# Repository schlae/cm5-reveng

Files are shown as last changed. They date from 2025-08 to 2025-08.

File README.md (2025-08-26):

# Reverse Engineered Raspberry Pi Compute Module 5

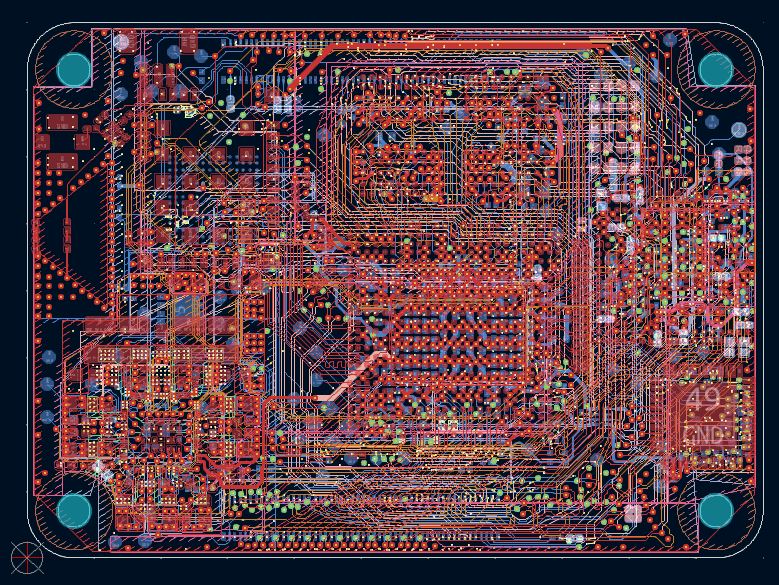
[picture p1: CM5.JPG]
Board layout with all the layers turned on


This is the reverse engineered schematic and layout for a Raspberry Pi
Compute Module 5. It's not meant to be fabricated--critical signal integrity
parameters aren't correct, it's not 100% faithful to the original, the
footprints aren't a perfect match, and the bill of materials is not
reverse engineered. You also won't be able to obtain most of the chips
since they are custom for this design or only available to large customers,
not through a distributor.

I'm sure folks will want the schematic of the regular Pi 5, but I don't
have plans to reverse engineer that.

[Schematic PDF](CM5RevEng.pdf)

[Bonus schematic of the RM0 WiFi/Bluetooth module](rpi-rm0/rpi-rm0.pdf)

## Why?

I needed to solve some design issues with a project that uses one of these
modules, but the schematic was not available. Fortunately, with a little
reverse engineering work, I was able to back out the schematic and solve my
design issues.

It's useful mainly for educational purposes or advanced hacking. For example,
now that the PMIC pinout is known, the I2C register map could be explored.
It's a great little part--if you accidentally blow up a CM5, you might be able
to remove everything except for the PMIC, program it over I2C, and use it
to power another project.

## How?

I removed all the parts from the board, measured them with an LCR meter (and
VNA, in the case of the ferrite beads), and then sanded down the board one
layer at a time, imaging each with a flatbed scanner at 9600 DPI. KiCad layout
lets you embed images which is great for tracing.

## Fun Trivia

The resistors in the upper right corner that select the memory and eMMC
configuration are not zero-ohm devices. Each possible position has a specific
resistor value, forming a resistor divider with a 10K resistor, so that
the RP1 can measure the voltage with two ADC inputs and determine the
configuration.

The board has 10 layers. It is what's known as a 2+6+2 configuration since
it has four layers of microvias: layer 1-2, 2-3, 8-9, and 9-10. There are
buried mechanical vias from layers 2-9, and standard through-board vias
from layers 1-10.

The PMIC has a hot-swap function to limit the inrush current to the
\>350uF of capacitance on the 5V rail. External capacitance on the carrier
board is probably unnecessary.

The WiFi and Bluetooth functions can be disabled (through GPIO) from the
BCM2712 as well as the connector pins. You can detect this externally
by monitoring the voltages on the BT\_nDISABLE and WL\_nDISABLE pins.

The CM5 with onboard eMMC will not conflict with an external SD card (wired
to the pins on the connector). This is because the SD pins are unconnected on
this version of the module.

The original board has no designators, so the ones in this design are
made up, with the exception of the test points, which are documented
in the official RPi datasheet.

The 5V input goes through a hot-swap circuit with a series pass MOSFET. Since
there is a test point on either side of the MOSFET and the part number is
known (DMG7430LFG), you could monitor the voltage across and compute the
supply current based on the MOSFET RDSON.

## Board Stackup

By very carefully sanding through the board one layer at a time, I figured
out the approximate stackup using digital calipers.

| Layer | | Approximate Thickness (mm) | Function |
|---|-|---|---|
| 1 | Cu | 0.0522 | Top layer |
| | PP | 0.0450 | |
| 2 | Cu | 0.0522 | Ground, PMIC LX, some signals. Reference layer for 1 and 3. |
| | PP | 0.0600 | |
| 3 | Cu | 0.0348 | Signal and power. |
| | PP | 0.1400 | |
| 4 | Cu | 0.0348 | Ground. |
| | Core | 0.0600 | |
| 5 | Cu | 0.0522 | Power, limited signal. |
| | PP | 0.1176 | |
| 6 | Cu | 0.0522 | Power. |
| | Core | 0.0600 | |
| 7 | Cu | 0.0348 | Ground. |
| | PP | 0.1400 | |
| 8 | Cu | 0.0348 | Signal and power. |
| | PP | 0.0348 | |
| 9 | Cu | 0.0522 | Ground. Reference layer for 8 and 10. |
| | PP | 0.0450 | |
| 10 | Cu | 0.0522 | Bottom layer | 

## Updated Test Point List

The Raspberry Pi Compute Module 5 datasheet has a table of test points, but
most of them are listed as "reserved." Here's a complete table. The coordinates
are relative to the lower left corner of the board (if the board had
a rectangular corner instead of being rounded off), increasing to the right
and upwards. Note that, in the KiCad layout, the lower left corner
is at 100mm x 100mm, and the Y axis is flipped, decreasing as you move
up. To change a coordinate from this table to KiCad, add 100 to the X
coordinate, and subtract the Y coordinate from 100.

| Reference | X | Y | NAME | DESCRIPTION |
|---|---|---|---|---|
| MH4 | 51.5  | 36.5  | Mounting Hole | |
| MH3 |  3.5  | 36.5  | Mounting Hole | |
| MH2 | 51.5  |  3.5  | Mounting Hole | |
| MH1 |  3.5  |  3.5  | Mounting Hole | |
| TP1 | 14.34 | 17.54 | +5V | Raw 5V power to board. |
| TP2 |  8.8  |  1.3  | RUN | Unknown PMIC status output, possibly power good. |
| TP3 | 51.2  | 32.6  | GND |
| TP4 |  4.8  | 13 | PMIC INT | PMIC interrupt output (likely). |
| TP7 | 24.2  |  7.5  | GND |
| TP8 |  1.65 | 15.05 | GND |
| TP9 |  1.5  | 10.05 | VREF\_3V3 | Analog 3.3V to RP1 for ADCs. |
| TP10 | 48.4  | 15.1  | VREG | Unknown regulated voltage to RP1. |
| TP13 | 42.6  |  7.3  | GND |
| TP15 | 14.7  |  6.6  | VDD\_0V8\_LDO | 0.8V LDO regulator to BCM2712. |
| TP16 |  9.3  | 34.9  | nRPIBOOT | Hold low for boot mode. |
| TP17 | 37.4  |  8.1  | VDD\_3V3\_2 | Secondary 3.3V rail for NOR flash and eMMC. |
| TP21 | 24.5125 | 14.025 | nRESET\_OUT | BCM2712 reset output (status). |
| TP22 | 13.0875 | 11.225 | PMIC\_SIG | Unknown PMIC signal. Could be for PMIC OTP programming. |
| TP26 | 17.7  | 20.2  | GND |
| TP27 | 43.6  | 22.3  | VDD\_1V1\_RP1 | RP1 1.1V core voltage supply. |
| TP28 | 15.4  | 16 | VDD\_BCM\_CORE | BCM2712 core voltage rail. Nominally 0.8V. |
| TP29 | 23.65 | 21.55 | VDD\_0V8\_BCM | BCM2712 auxiliary 0.8V rail. |
| TP30 | 37.2  | 34.9  | VDD\_0V6 | LPDDR4 VDDQ supply. |
| TP31 |  9.1  |  3.2  | VDD\_1V1 | LPDDR4 VDD2 supply. |
| TP32 |  1.5  | 13 | VDD\_3V7\_WIFI | 3.7V rail for WiFi radio. |
| TP33 | 47 | 36 | CM5\_3V3 | Main 3.3V supply rail. |
| TP34 | 50.5  | 15.5  | CM5\_1V8 | Main 1.8V supply rail. |
| TP35 | 11 | 37.8  | DEBUG\_UART\_TX | Debugging UART transmit output. |
| TP36 |  8.5  | 37.1  | DEBUG\_UART\_RX | Debugging UART receive input. |
| TP39 | 22.1  |  6.1  | EN\_LOAD\_SWITCH | Enables VDD\_3V3\_2 and VDD\_1V8\_2 when asserted. |
| TP40 |  6.7  | 15.2  | PMIC\_SCL | PMIC I2C bus clock. |
| TP41 |  8.7  | 15.3  | PMIC\_SDA | PMIC I2C bus data. |
| TP42 | 11.4  | 34.9  | PWR\_BUT | Power button signal to PMIC. |
| TP44 | 51.7  | 30.2  | VDD\_2V5\_RP1 | RP1 internal voltage regulator: 2.5V supply. |
| TP45 | 53.1  | 28.7  | VDD\_1V1\_RP1 | RP1 internal voltage regulator: 1.1V supply. |
| TP46 |  7 | 34.7  | GND |
| TP48 | 21.6  | 15.4  | SOC\_TRST\_N | BCM2712 JTAG test reset input. |
| TP49 | 21.6  | 13.3  | SOC\_TDI | BCM2712 JTAG test data input. |
| TP50 | 20.4  | 17.2  | SOC\_TDO | BCM2712 JTAG test data output. |
| TP51 | 20.3  |  8.8  | SOC\_TMS | BCM2712 JTAG test mode select. |
| TP52 | 19.9  | 11.9  | SOC\_TCK | BCM2712 JTAG test clock. |
| TP57 | 53.2  | 32 | RP1\_TP | Unknown RP1 signal. |
| TP60 | 48 | 38.7  | GND |
| TP61 | 6.575 | 1.225 | GND |
| TP62 | 22.2  | 31.6  | GND |
| TP63 |  8.7  | 18.2  | 5V\_SENSE | Main board 5V rail, after hot-swap/inrush limiting MOSFET. |
| TP64 | 47.3  |  5.4  | VDD\_1V0\_PHY | BCM54210 internal voltage regulator: 1.0V supply. |
| TP65 | 28.2  |  7.5  | USBC\_D\_N | BCM2712 USB 2.0. |
| TP66 | 26.1  |  7.5  | USBC\_D\_P | BCM2712 USB 2.0. |
| TP67 |  7 | 38.6  | LED\_nPWR | Power LED, driven by RP1. |
| TP68 | 13 | 37.5  | LED\_nACT | Activity LED, driven by BCM2712. |
| TP69 | 38.8  | 25.9  | ETH0\_P |
| TP70 | 39.6  | 24.2  | ETH0\_N |
| TP71 | 43.8  | 14.1  | ETH1\_N |
| TP72 | 45.6  | 13.1  | ETH1\_P |
| TP73 | 42.4  | 31.7  | ETH2\_P |
| TP74 | 42.6  | 33.7  | ETH2\_N |
| TP75 | 41.6  | 37.8  | ETH3\_P |
| TP76 | 42.9  | 36.1  | ETH3\_N |
| TP77 | 14.37 | 19.52 | +5V | Raw 5V power to board. |

## RP1 Pinout Mysteries

There are some pins that have not been identified because they're not connected
on the CM5:

| Pin | Guess |
|-----|---|
| A2  | |
| B3  | |
| C2  | |
| C3  | |
| C4  | |
| D1  | |
| E3  | |
| E10  | |
| E15  | |
| F1  | |
| F2  | |
| F3  | |
| F7  | |
| G1  | |
| G2  | |
| H1  | |
| H3  | |
| H7  | |
| H17 | USB 2.0? |
| H18 | USB 2.0? |
| J15  | |
| J17  | |
| L13  | |
| L15  | |
| M17  |USB 2.0? |
| M18  |USB 2.0? |
| R4  | |
| T3  | |
| T4  | |
| T13  | |
| T14  | |
| V2  | |
| V3  | |

## Future Work

* PCIe (BCM2712 to RP1) net identification
* RP1 to BCM2712 net identification
* PMIC I2C register map

## License

[CC BY-SA 4.0](https://creativecommons.org/licenses/by-sa/4.0)

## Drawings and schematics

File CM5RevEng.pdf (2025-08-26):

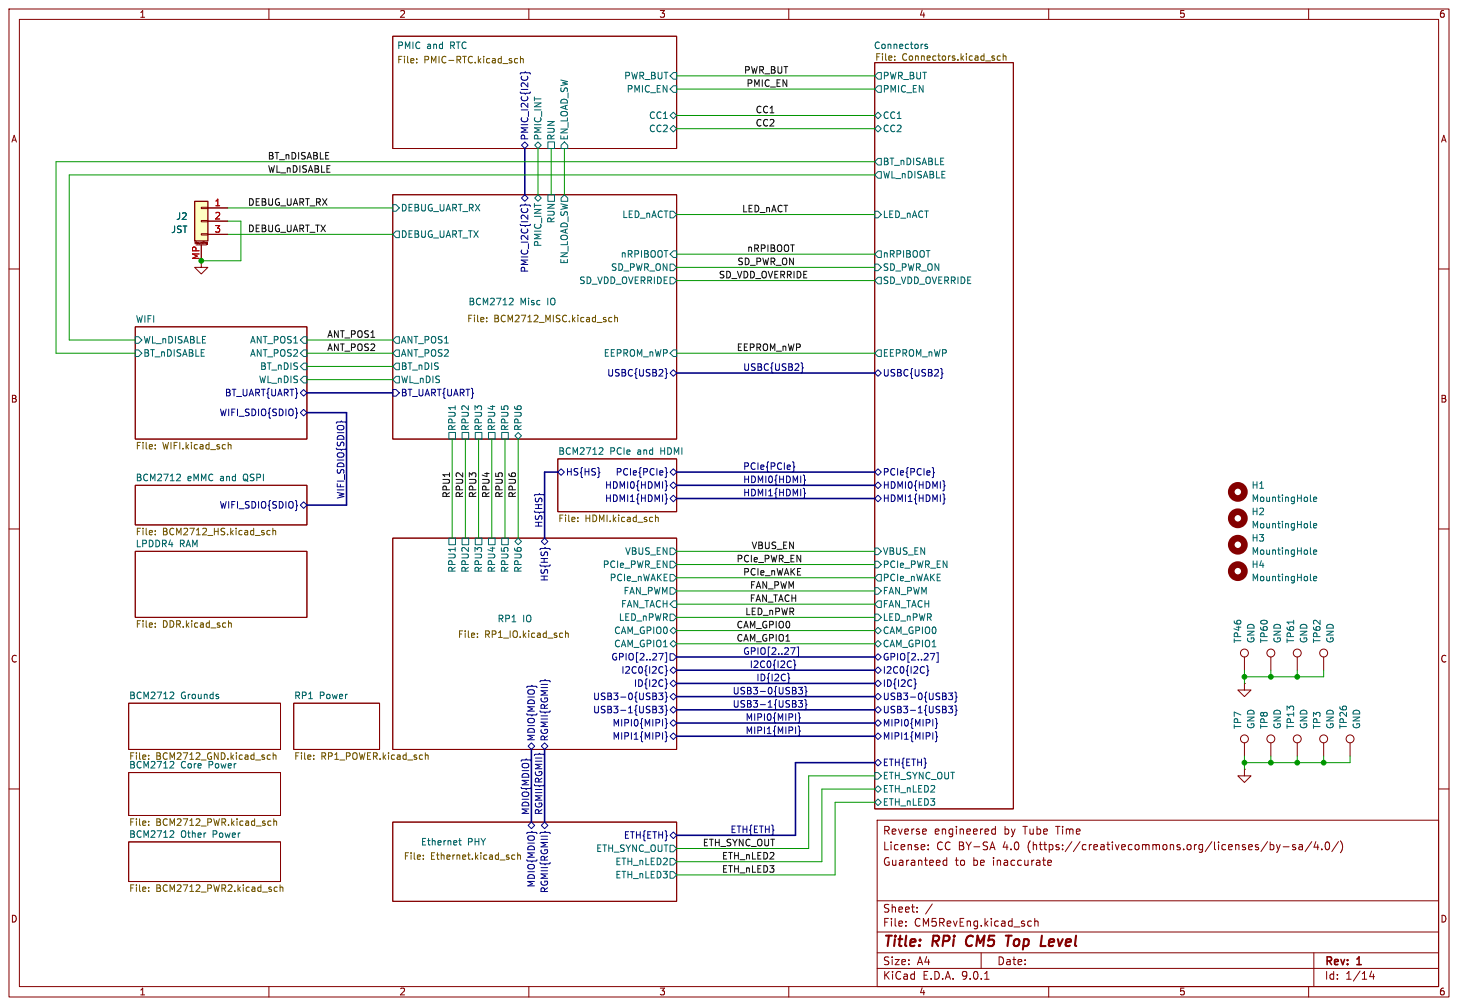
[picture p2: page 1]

File: RP1_IO.kicad_sch WIFI_SDIO{SDIO} BCM2712 eMMC and QSPI File: BCM2712_HS.kicad_sch BT_nDISABLE

H1 MountingHole TP3 GND TP26 GND TP61 GND TP62 GND

H4 MountingHole H3 MountingHole H2 MountingHole TP46 GND

ID{I2C} MDIO{MDIO} RGMII{RGMII} RP1 IO

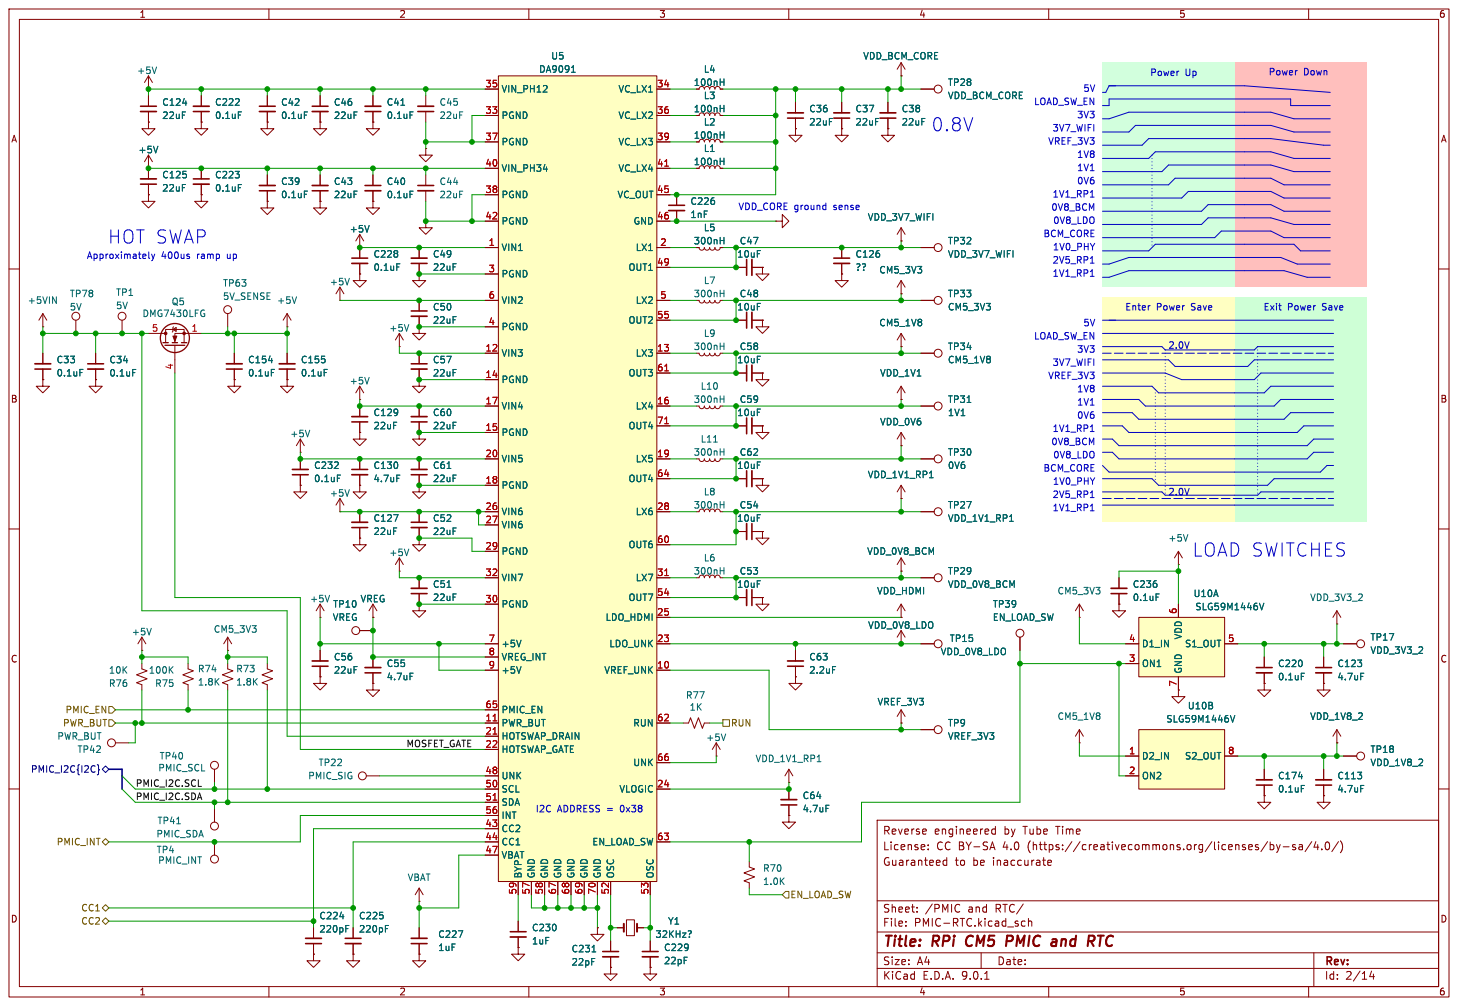
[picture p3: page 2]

Id: 2/14 Title: RPi CM5 PMIC and RTC

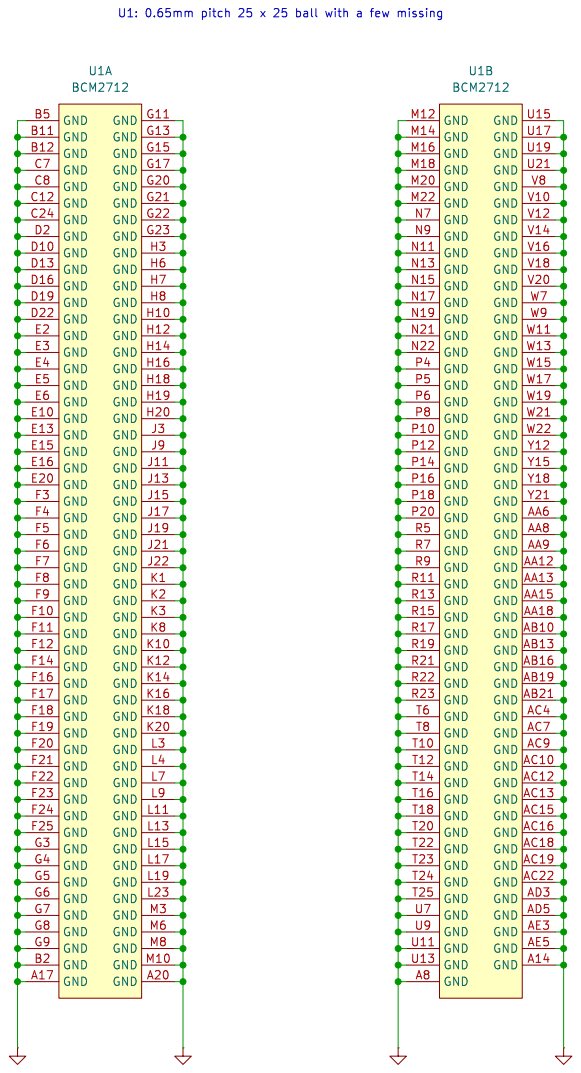
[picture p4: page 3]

BCM2712 GND J9 GND J11 GND J13 GND J15 GND J17 GND J19 GND J21 GND J22 GND K1 GND K2 GND K3 GND K8 GND K10 GND K12 GND K14 GND K16 GND K18 GND K20 GND L3 GND L4 GND L7 GND L9 GND L11 GND L13 GND L15 GND L17 GND L19 GND L23 GND M3 GND M6 GND M8 GND M10
GND B5 GND B11 GND B12 GND C7 GND C8 GND C12 GND C24 GND D2 GND D10 GND D13 GND D16 GND D19 GND D22 GND E2 GND E3 GND E4 GND E5 GND E6 GND E10 GND E13 GND E15 GND E16 GND E20 GND F3 GND F4 GND F5 GND F6 GND F7 GND F8 GND F9 GND F10 GND F11 GND F12 GND F14 GND F16 GND F17 GND F18 GND F19 GND F20 GND F21 GND F22 GND F23 GND F24 GND F25 GND G3 GND G4 GND G5 GND G6 GND G7 GND G8 GND G9 GND B2 GND A17

BCM2712U1: 0.65mm pitch 25 x 25 ball with a few missing
GND G11 GND G13 GND G15 GND G17 GND G20 GND G21 GND G22 GND G23 GND H3 GND H6 GND H7 GND H8 GND H10 GND H12 GND H14 GND H16 GND H18 GND H19 GND H20 GND J3 GND A20

Id: 3/14 Title: RPi CM5 BCM2712 Grounds

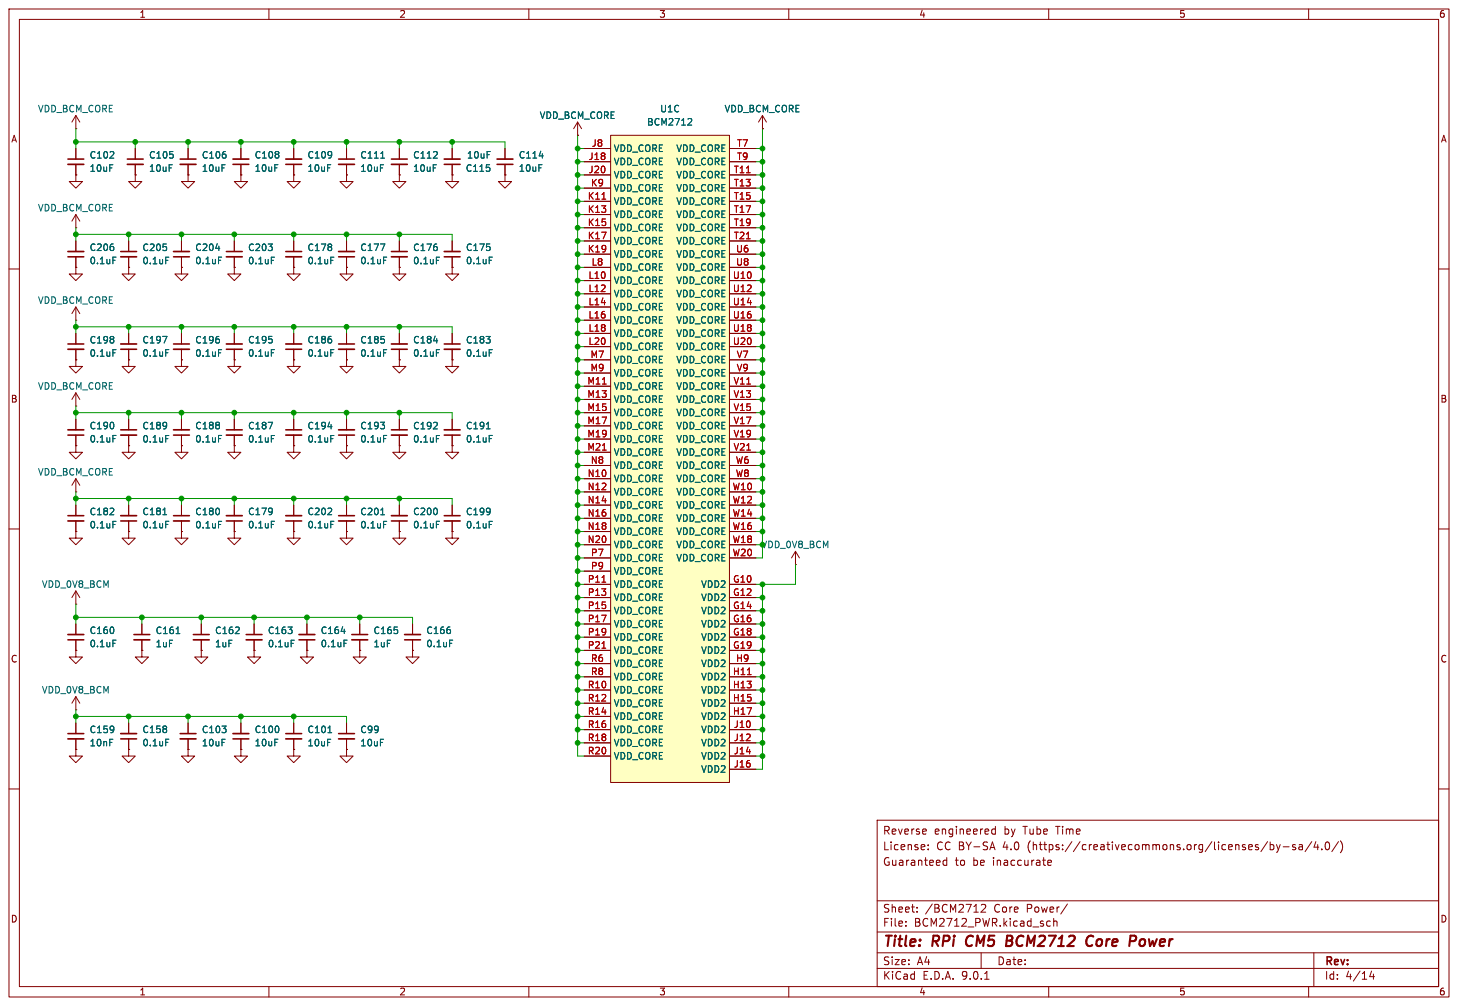
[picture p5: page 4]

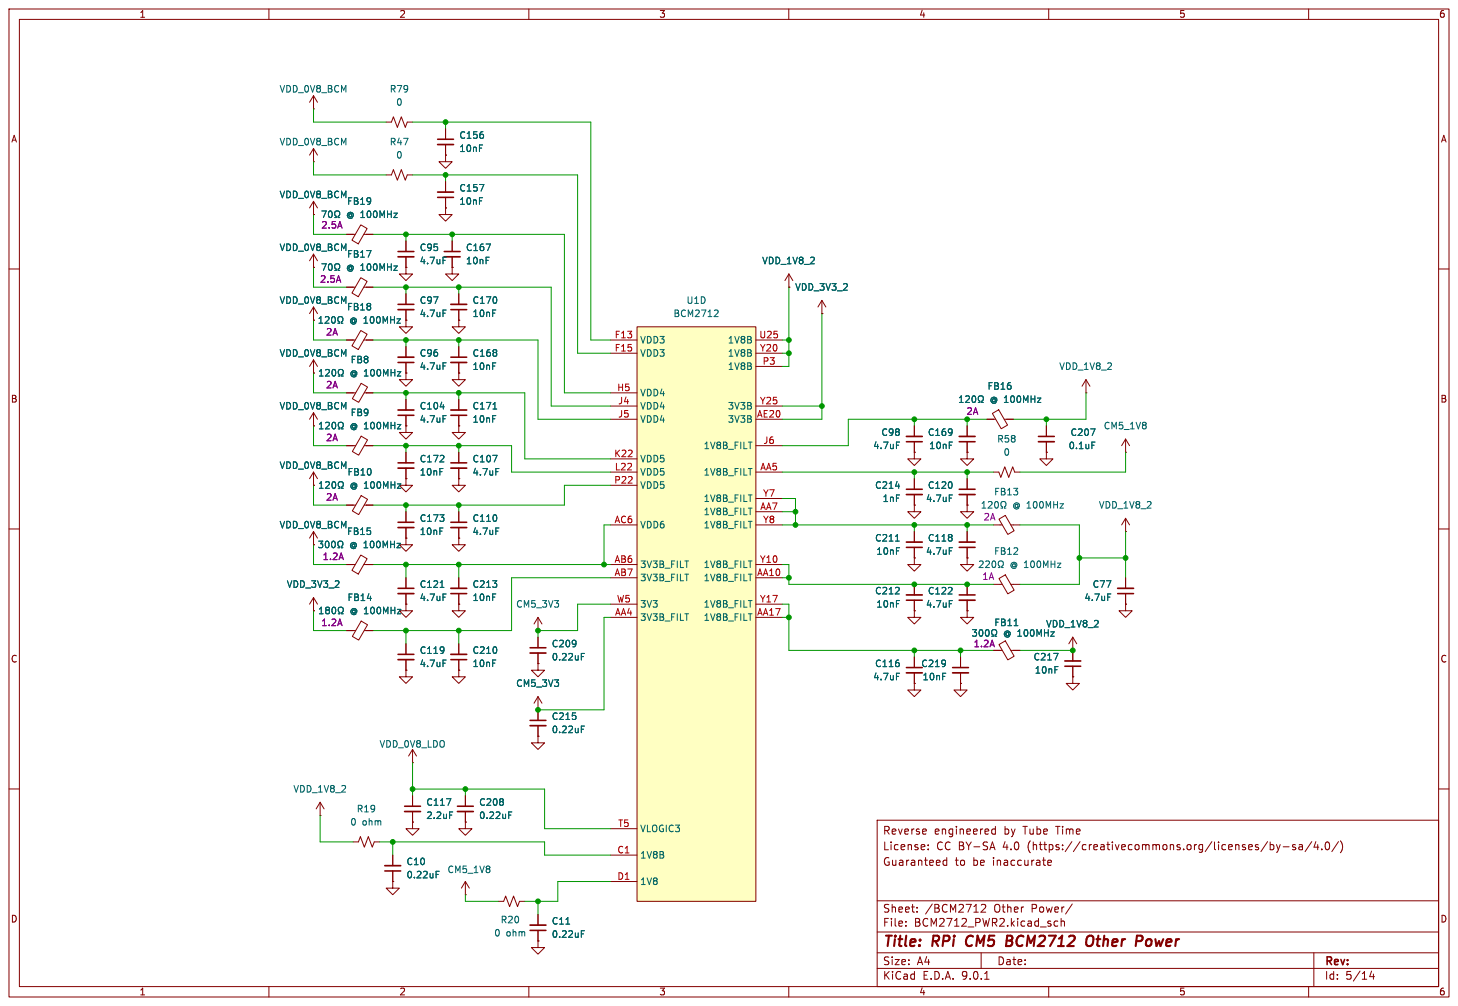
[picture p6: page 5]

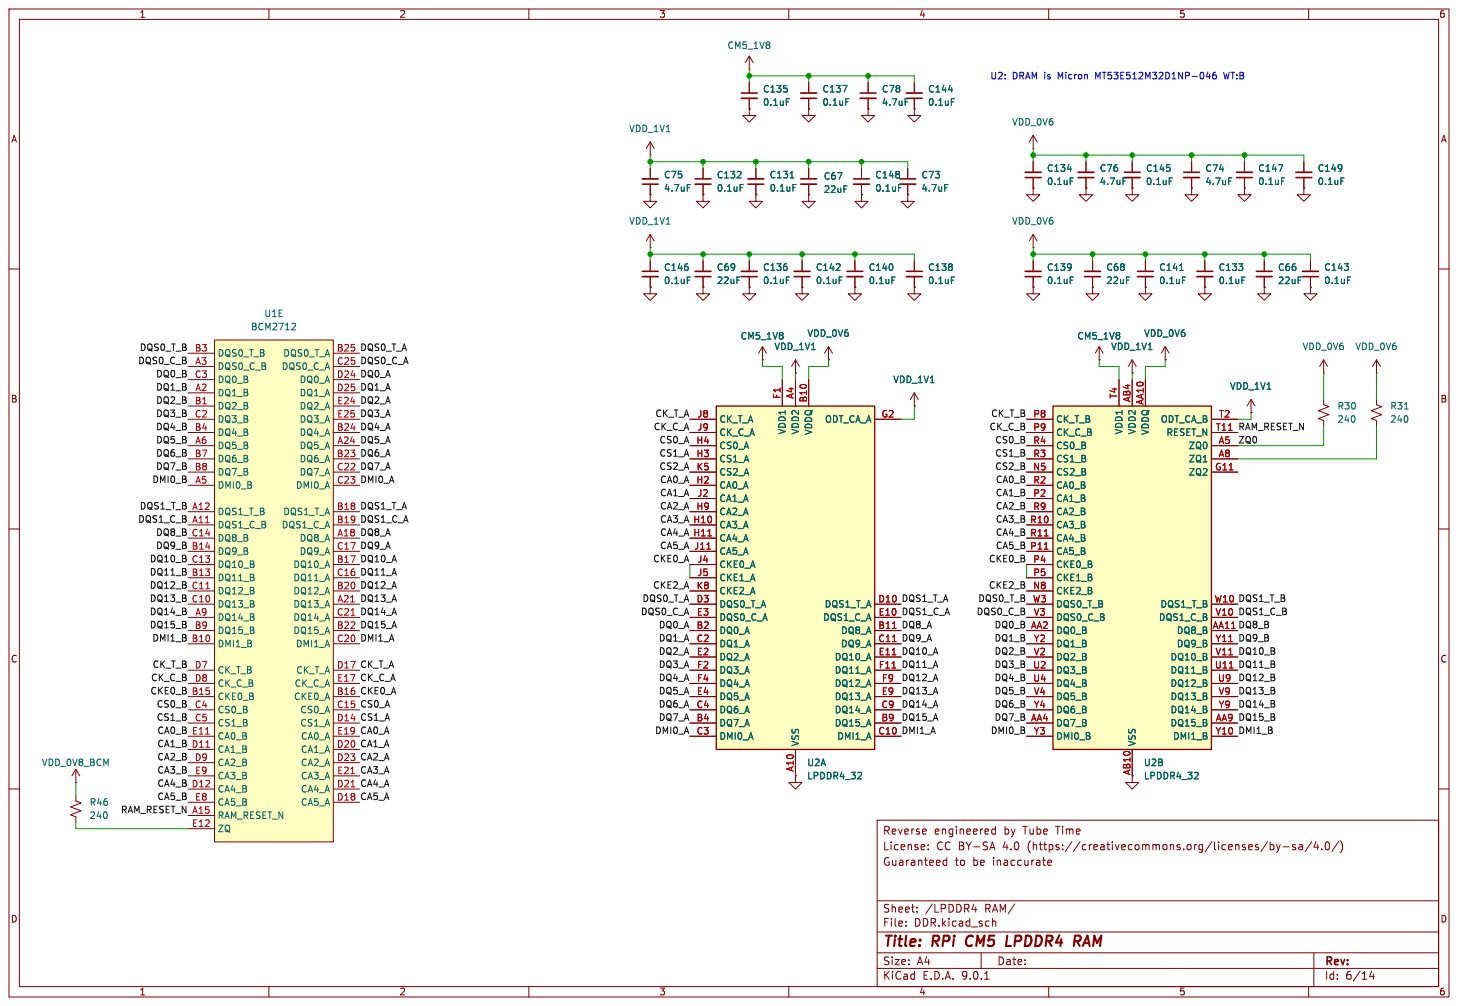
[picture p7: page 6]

Id: 6/14 Title: RPi CM5 LPDDR4 RAM

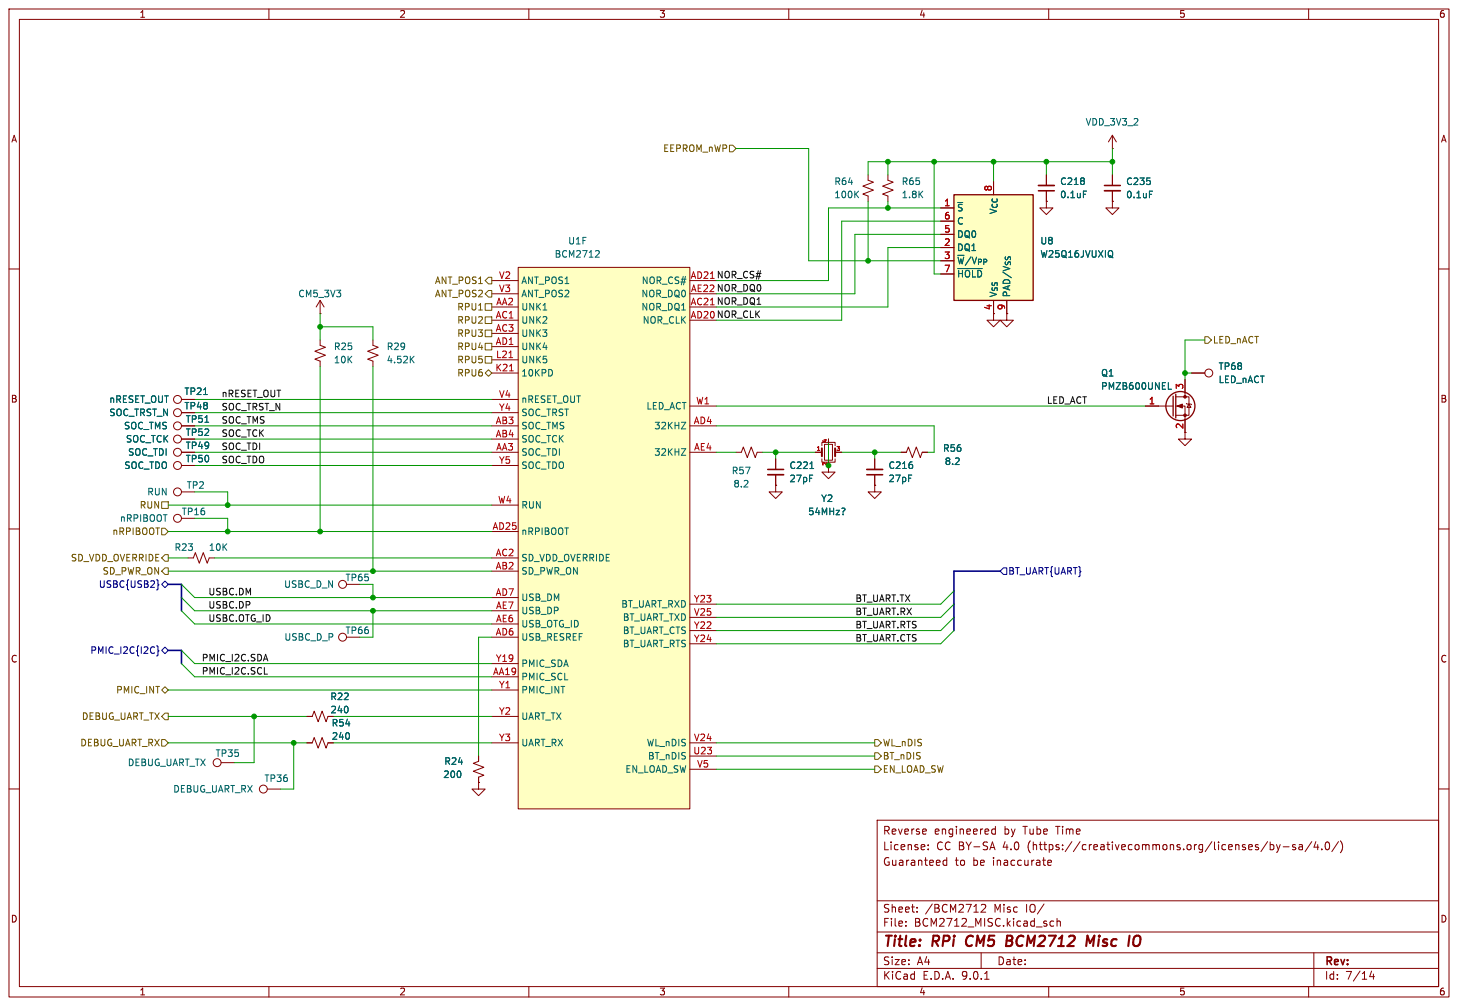
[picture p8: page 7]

PMIC_I2C.SDA USBC.DP USBC.OTG_ID

Id: 7/14 Title: RPi CM5 BCM2712 Misc IO

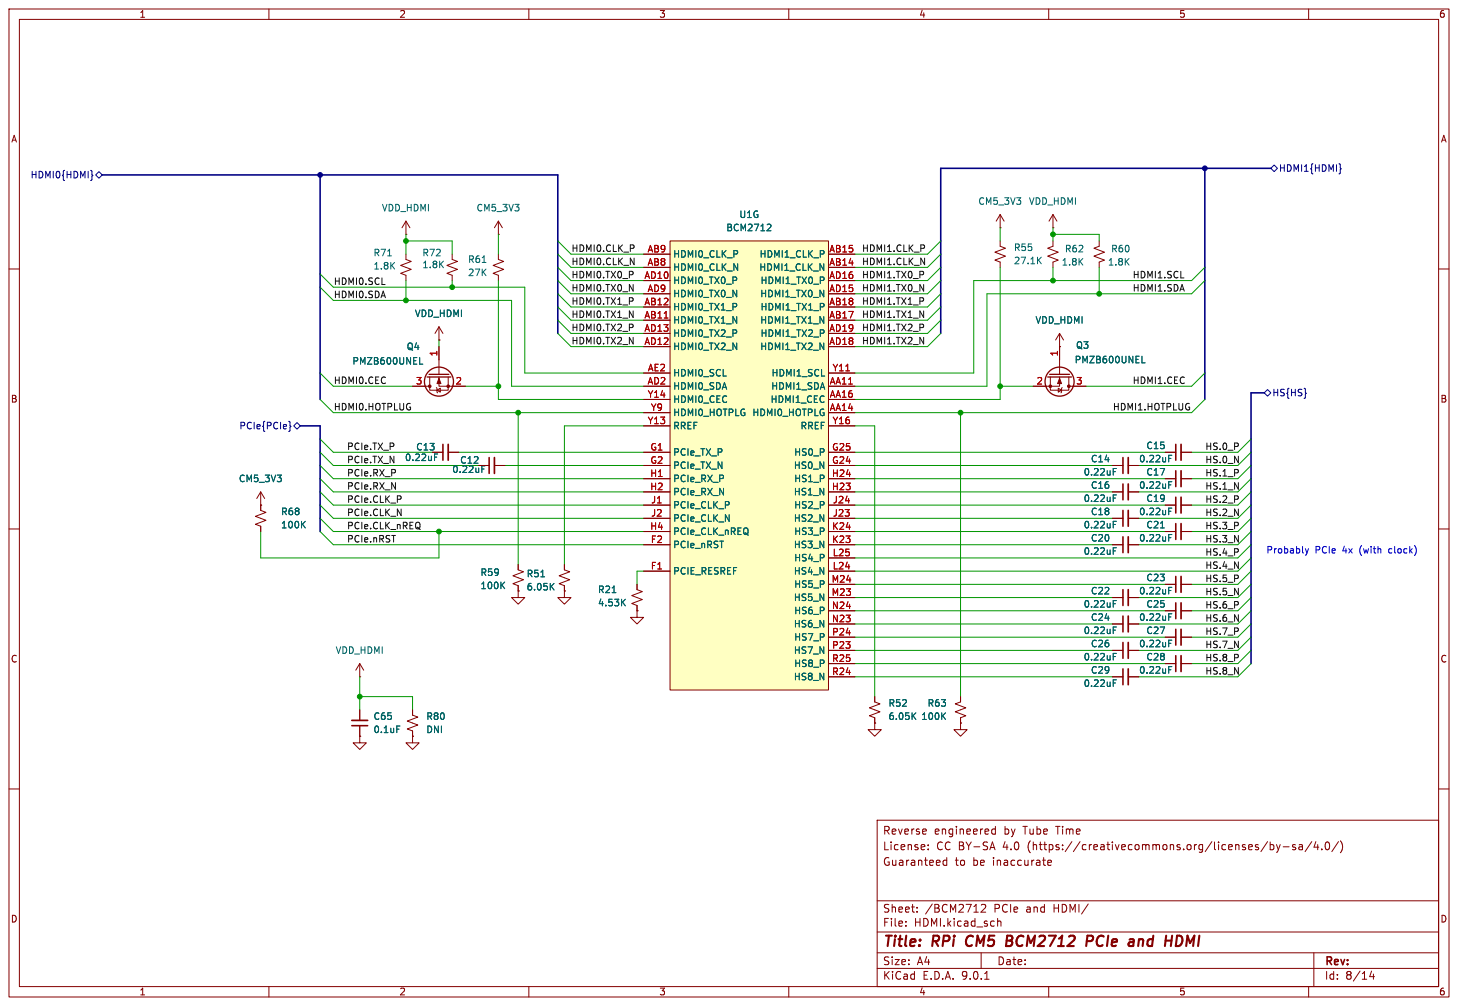
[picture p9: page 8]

Probably PCIe 4x (with clock) Q3 PMZB600UNEL

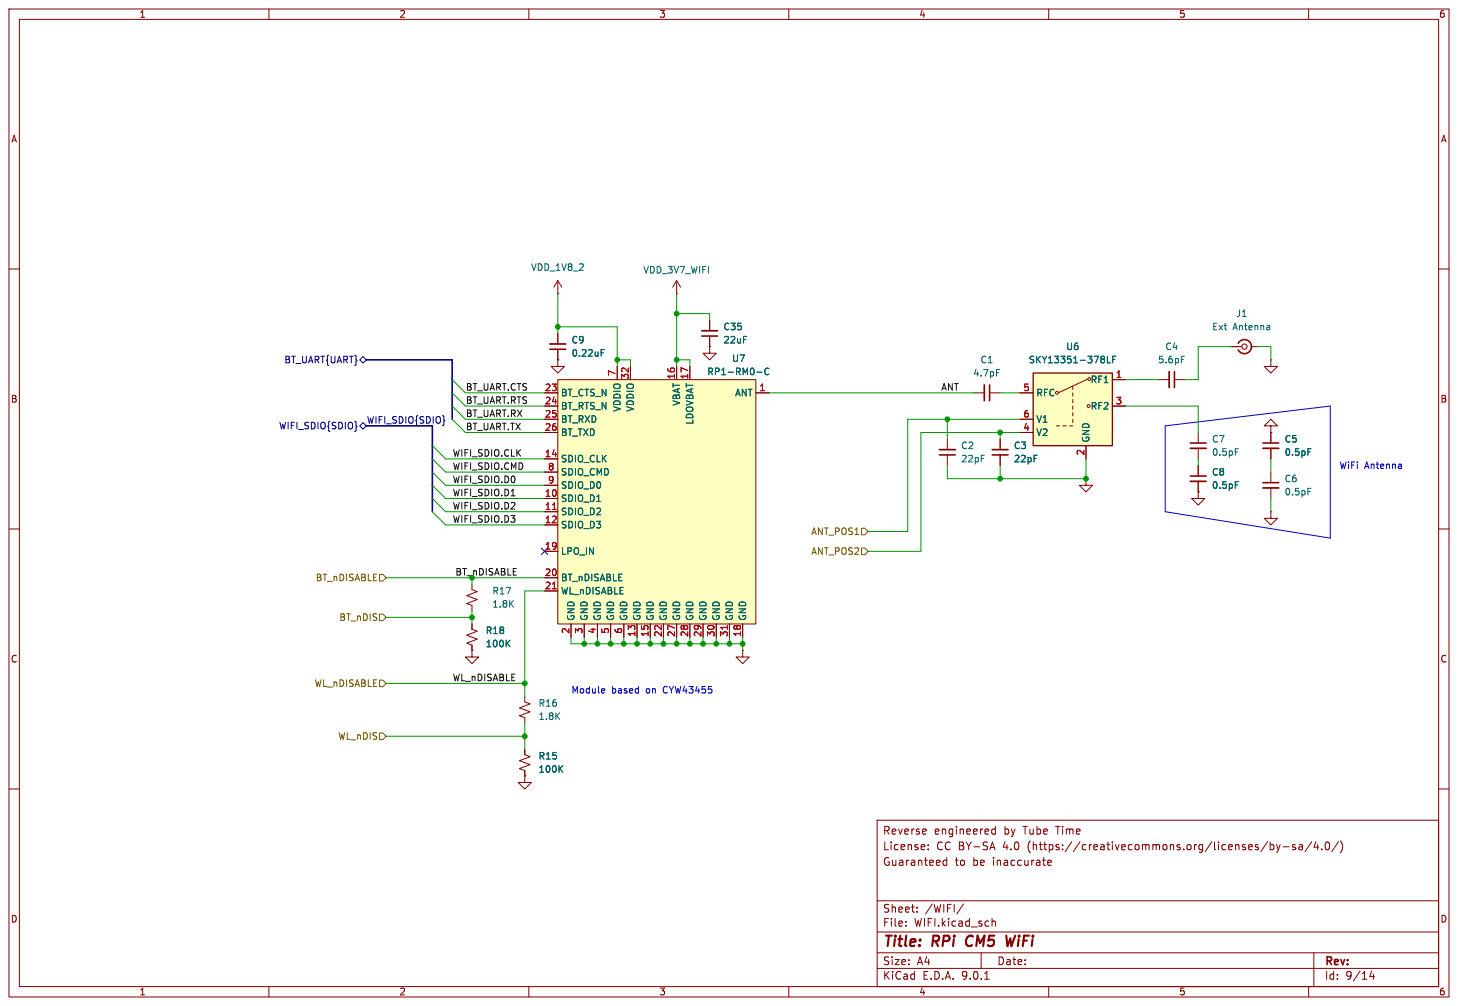
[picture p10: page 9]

6 VDDIO 32 GND 13 GND 15 GND 22 VBAT 16 GND 27 LDOVBAT 17 GND 28 GND 29 GND 30 GND 31 GND 18 ANT 1 C9

6 VDDIO 32 GND 13 GND 15 GND 22 VBAT 16 GND 27 LDOVBAT 17 GND 28 GND 29 GND 30 GND 31 GND 18 ANT 1 U7 RP1-RM0-C

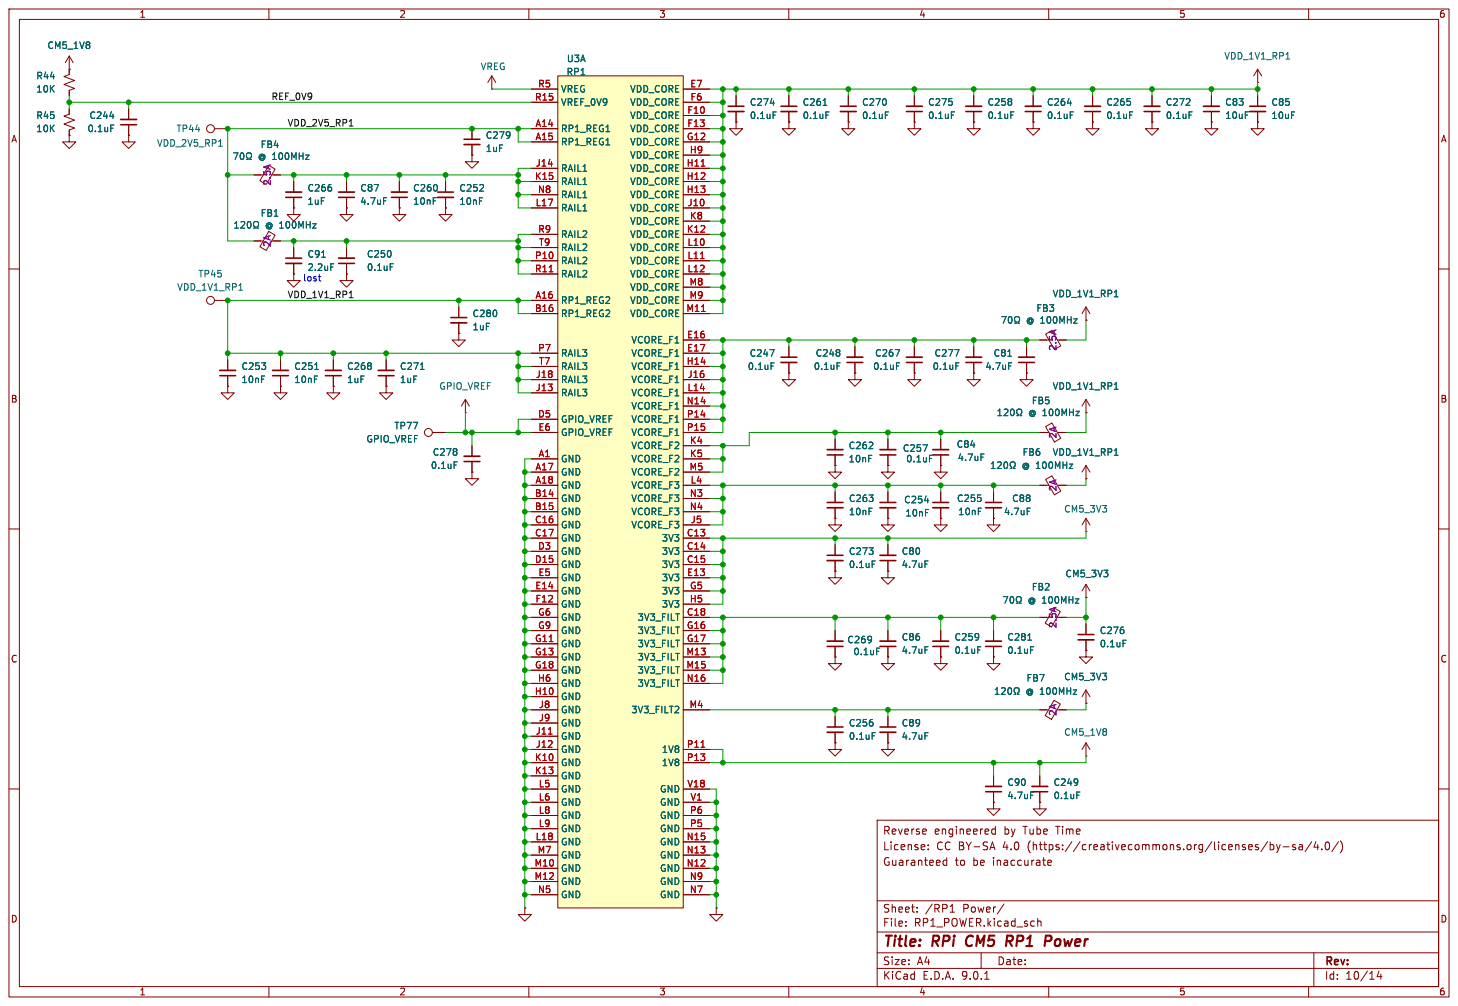
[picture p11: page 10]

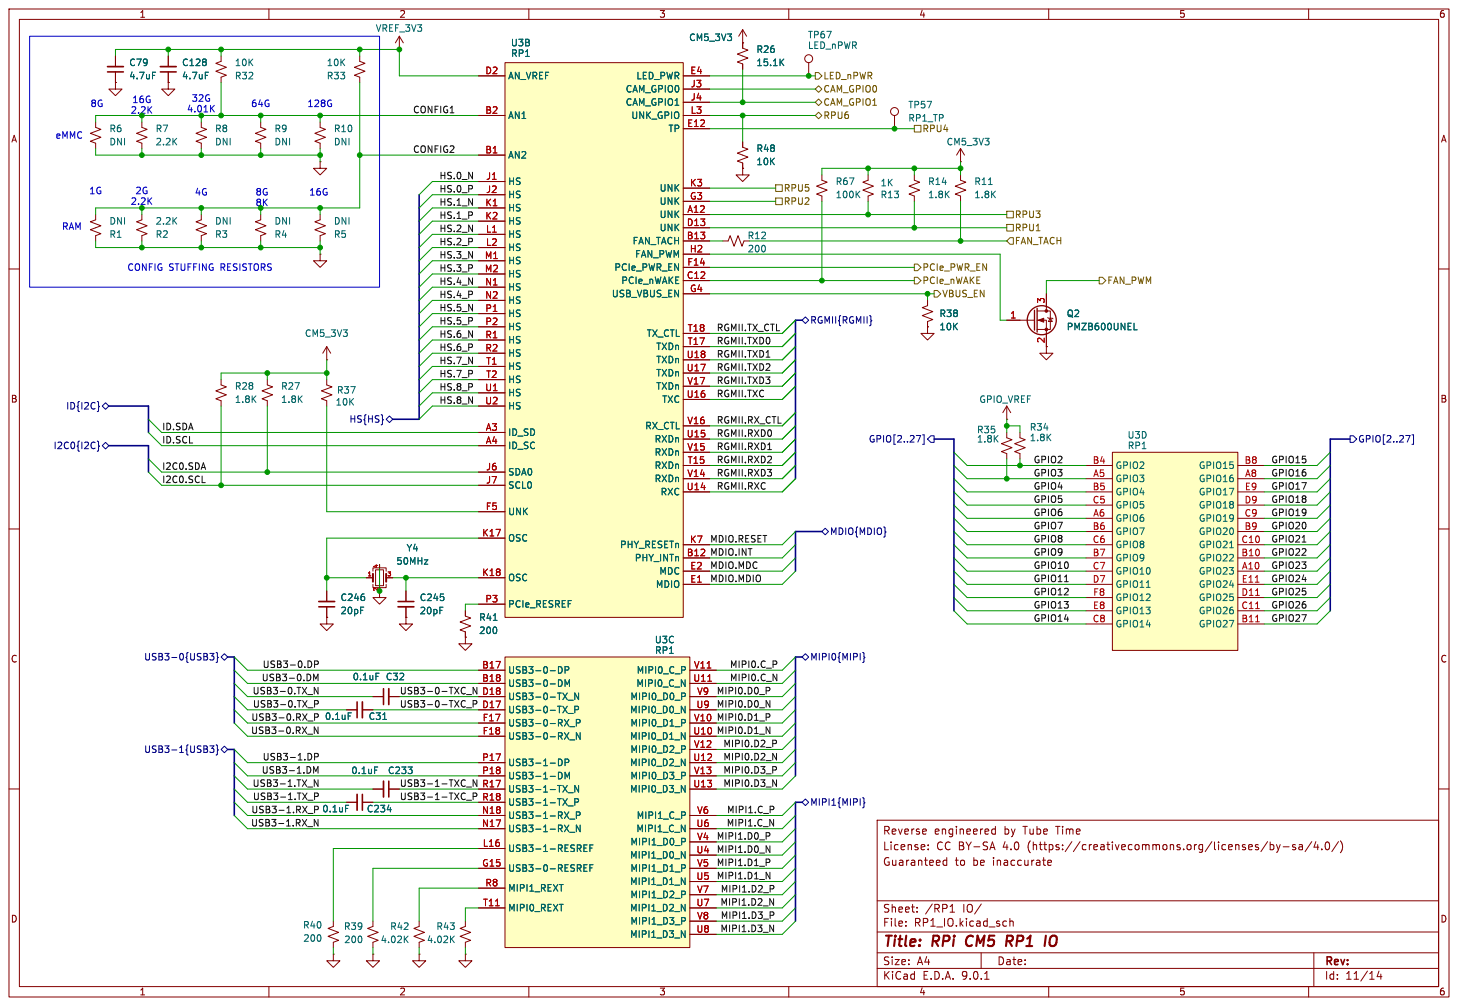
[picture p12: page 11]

Id: 11/14 Title: RPi CM5 RP1 IO

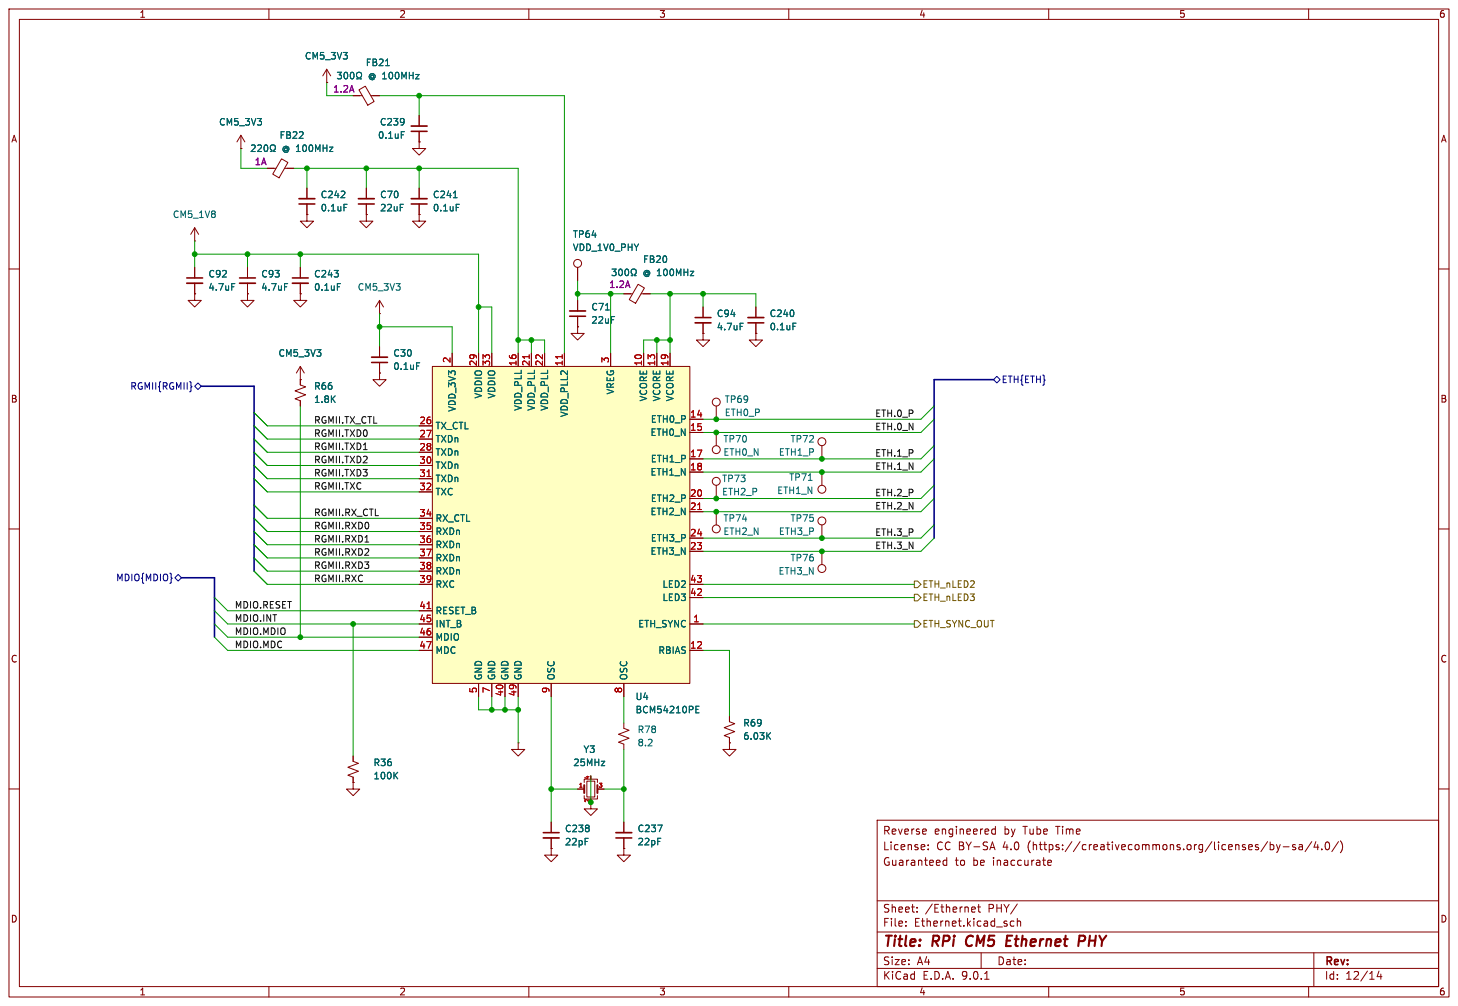
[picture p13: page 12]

ETH{ETH} ETH_SYNC_OUT ETH_nLED3 RGMII.RXD0 RGMII.RXC MDIO.INT MDIO.MDIO

RGMII.RXD3 RGMII.TXD3 RGMII.TXC

Id: 12/14 Title: RPi CM5 Ethernet PHY



USBC.DM
I2C0.SCL MIPI1.C_P MIPI1.D2_N MIPI1.D2_P USB3-1.DP USBC.DP HDMI0.CEC

Id: 14/14 Title: RPi CM5 Connectors
